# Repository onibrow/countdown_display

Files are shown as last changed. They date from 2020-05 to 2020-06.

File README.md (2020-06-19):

# Countdown Display

A low power countdown display

## Manual

### On / Off

The slide switch in the right position (closer to the edge of the device) is the "Discharge" or ON mode. The slide switch in the left position (closer to the middle of the device) is the "Charge / OFF" mode.

### Charging

To charge the battery, put the slide switch into the "Charge / OFF" mode - this will disconnect the battery from the rest of the device and enable it to be charged. At this state, the display will no longer turn on. Plug in a microUSB cable to the port and watch the indicator LED turn on. If RED, the battery is charging - if GREEN, the charge is complete. From fully discharged to fully charged, it will take about 2.5 hours.

### Safety

As this device has all of its electrical components exposed, do not touch this with wet hands or poke it with metal / conductive objects. There are safety electronics in play to prevent the battery from over-currenting and frying itself, it is generally not a great idea to mess around with LiPo batteries. 

## Features

### 128x32 OLED Display

[SSD1306](https://smile.amazon.com/gp/product/B07X35H728/ref=ppx_yo_dt_b_asin_title_o06_s00?ie=UTF8&psc=1) 128x32 OLED display compatible with Adafruit's [OLED library](https://github.com/adafruit/Adafruit_SSD1306), featuring a shut down mode for low power consumption, capable of running off 3.6V to 5V.

### Low Power

ATMega328P was chosen for the microcontroller of choice, for its low power sleep feature and small footprint. Running off of a LiPo battery, it can enter a deep sleep that consumes less that 10uA of current utilizing the external interrupt (generated using a push button) based indefinite sleep, from the [Arduino LowPower library](https://www.arduino.cc/en/Reference/ArduinoLowPower). The fuses are burned to use an 8MHz external clock and to brown out at 3V.

### RTC

A real time clock was used to keep track of the current date and time, running off of an ultra low power DS3231 and a back up coin cell. With the coin cell, the time keeping feature can run for 5 years, while the ultra low power could be directly sourced from one of the digital output pins on the ATMega to make power on and off of the RTC much easier. The Adafrtui [RTClib](https://github.com/adafruit/RTClib) was used for this chip.

### LiPo

A 40mAh LiPo battery was chosen as the main power supply for this device. Considering an ON current of about 12mA and a deep sleep current of 10uA, a quick calculation assuming that the device will be powered on for 2 minutes in any given day leaves the device an astounding 2 month life on a single charge. It is also equiped with an [MCP73831](https://www.microchip.com/wwwproducts/en/en024903) single cell, LiPo charge management controller to recharge the battery safely over a microUSB connection.

## Gallery



gif

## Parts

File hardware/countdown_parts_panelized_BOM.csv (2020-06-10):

Comment | Designator | Footprint | LCSC Part
20pF | C100 | 402 | C1554
20pF | C200 | 402 | C1554
4.7uF | C300 | 402 | C23733
4.7uF | C400 | 402 | C23733
0.1uF | C500 | 402 | C1525
0.1uF | C600 | 402 | C1525
1uF | C700 | 402 | C52923
0.1uF | C800 | 402 | C1525
Red | D100 | LED_0603 | C2286
Green | D200 | LED_0603 | C72043
330R | R100 | 402 | C25104
51k | R200 | 402 | C25794
1k | R300 | 402 | C11702
10k | R400 | 402 | C25744
10k | R500 | 402 | C25744
10k | R600 | 402 | C25744
330R | R700 | 402 | C25104
DS3231 | U100 | SOIC-8_3.9x4.9x1.27P | C107410
ATMEGA328P | U200 | TQFP-32_7.0x7.0x0.8P | C14877
MCP73831 | U300 | SOT-23-5 | C424093
BL1551 | U400 | SOT-363 | C82528
8Mhz | Y100 | SMD-5032_2P | C115962
20pF | C110 | 402 | C1554
20pF | C210 | 402 | C1554
4.7uF | C310 | 402 | C23733
4.7uF | C410 | 402 | C23733
0.1uF | C510 | 402 | C1525
0.1uF | C610 | 402 | C1525
1uF | C710 | 402 | C52923
0.1uF | C810 | 402 | C1525
Red | D110 | LED_0603 | C2286
Green | D210 | LED_0603 | C72043
330R | R110 | 402 | C25104
51k | R210 | 402 | C25794
1k | R310 | 402 | C11702
10k | R410 | 402 | C25744
10k | R510 | 402 | C25744
10k | R610 | 402 | C25744
330R | R710 | 402 | C25104
DS3231 | U110 | SOIC-8_3.9x4.9x1.27P | C107410
ATMEGA328P | U210 | TQFP-32_7.0x7.0x0.8P | C14877
MCP73831 | U310 | SOT-23-5 | C424093
BL1551 | U410 | SOT-363 | C82528
8Mhz | Y110 | SMD-5032_2P | C115962

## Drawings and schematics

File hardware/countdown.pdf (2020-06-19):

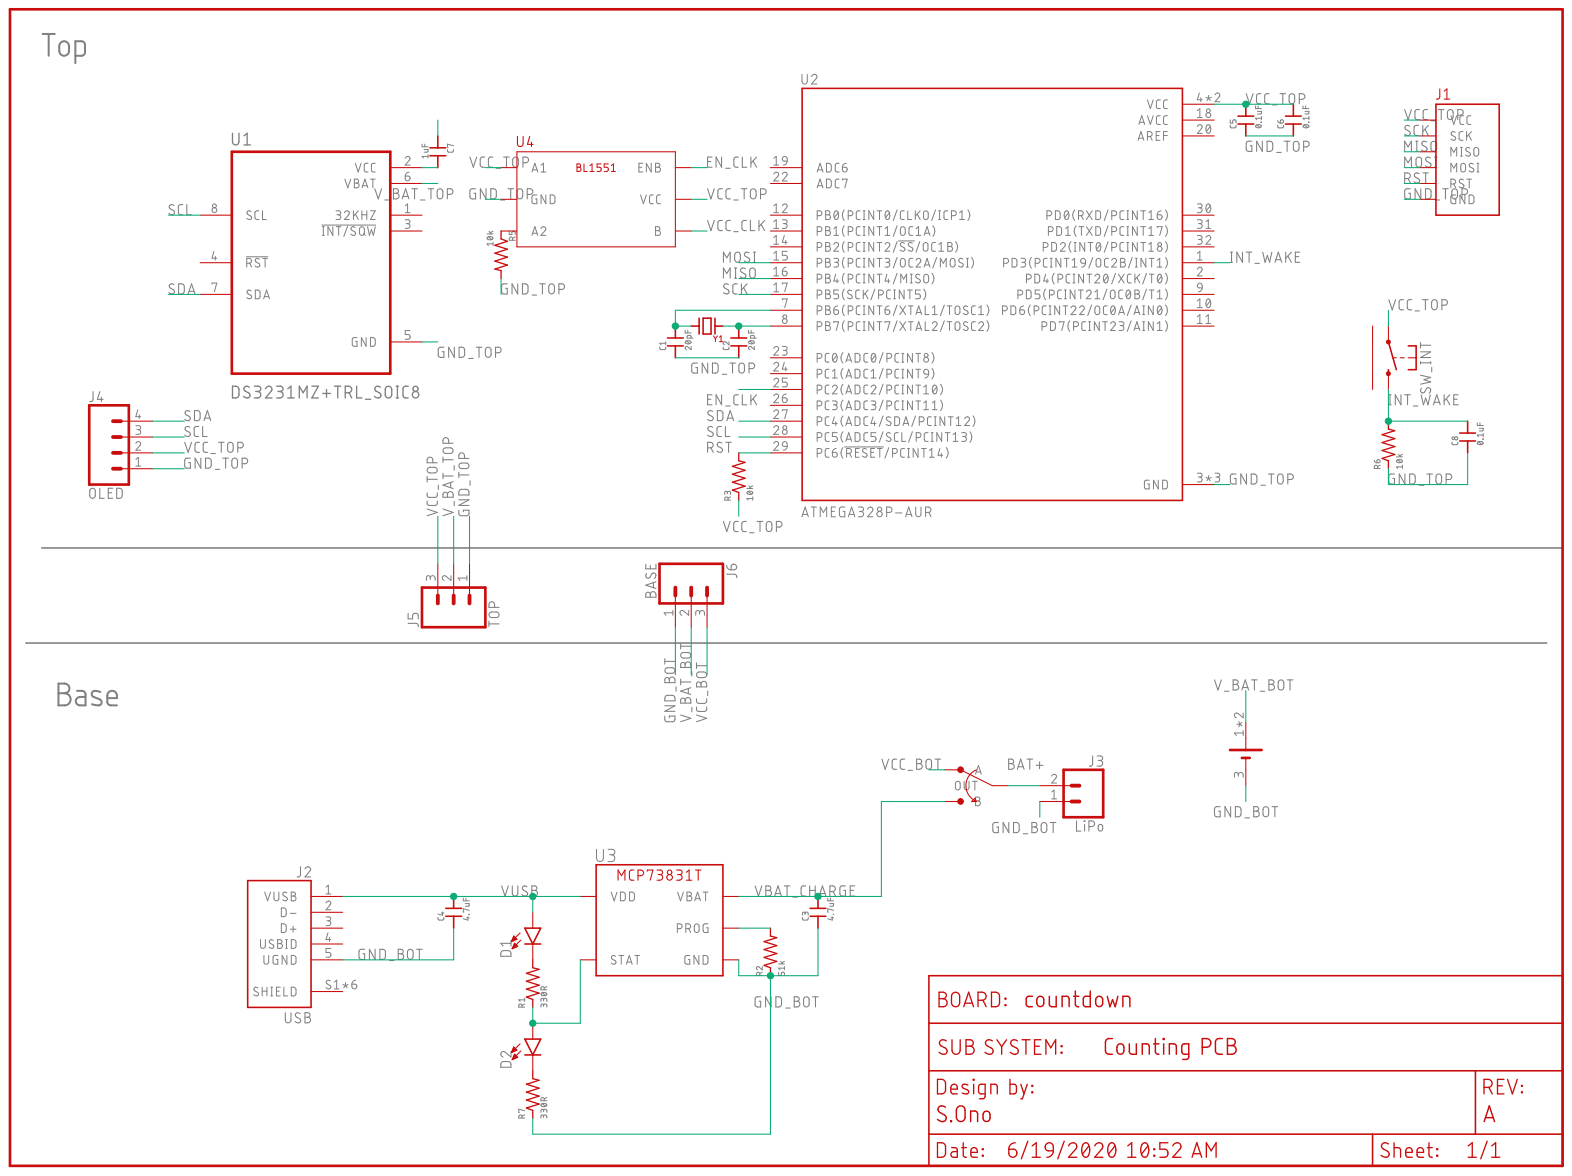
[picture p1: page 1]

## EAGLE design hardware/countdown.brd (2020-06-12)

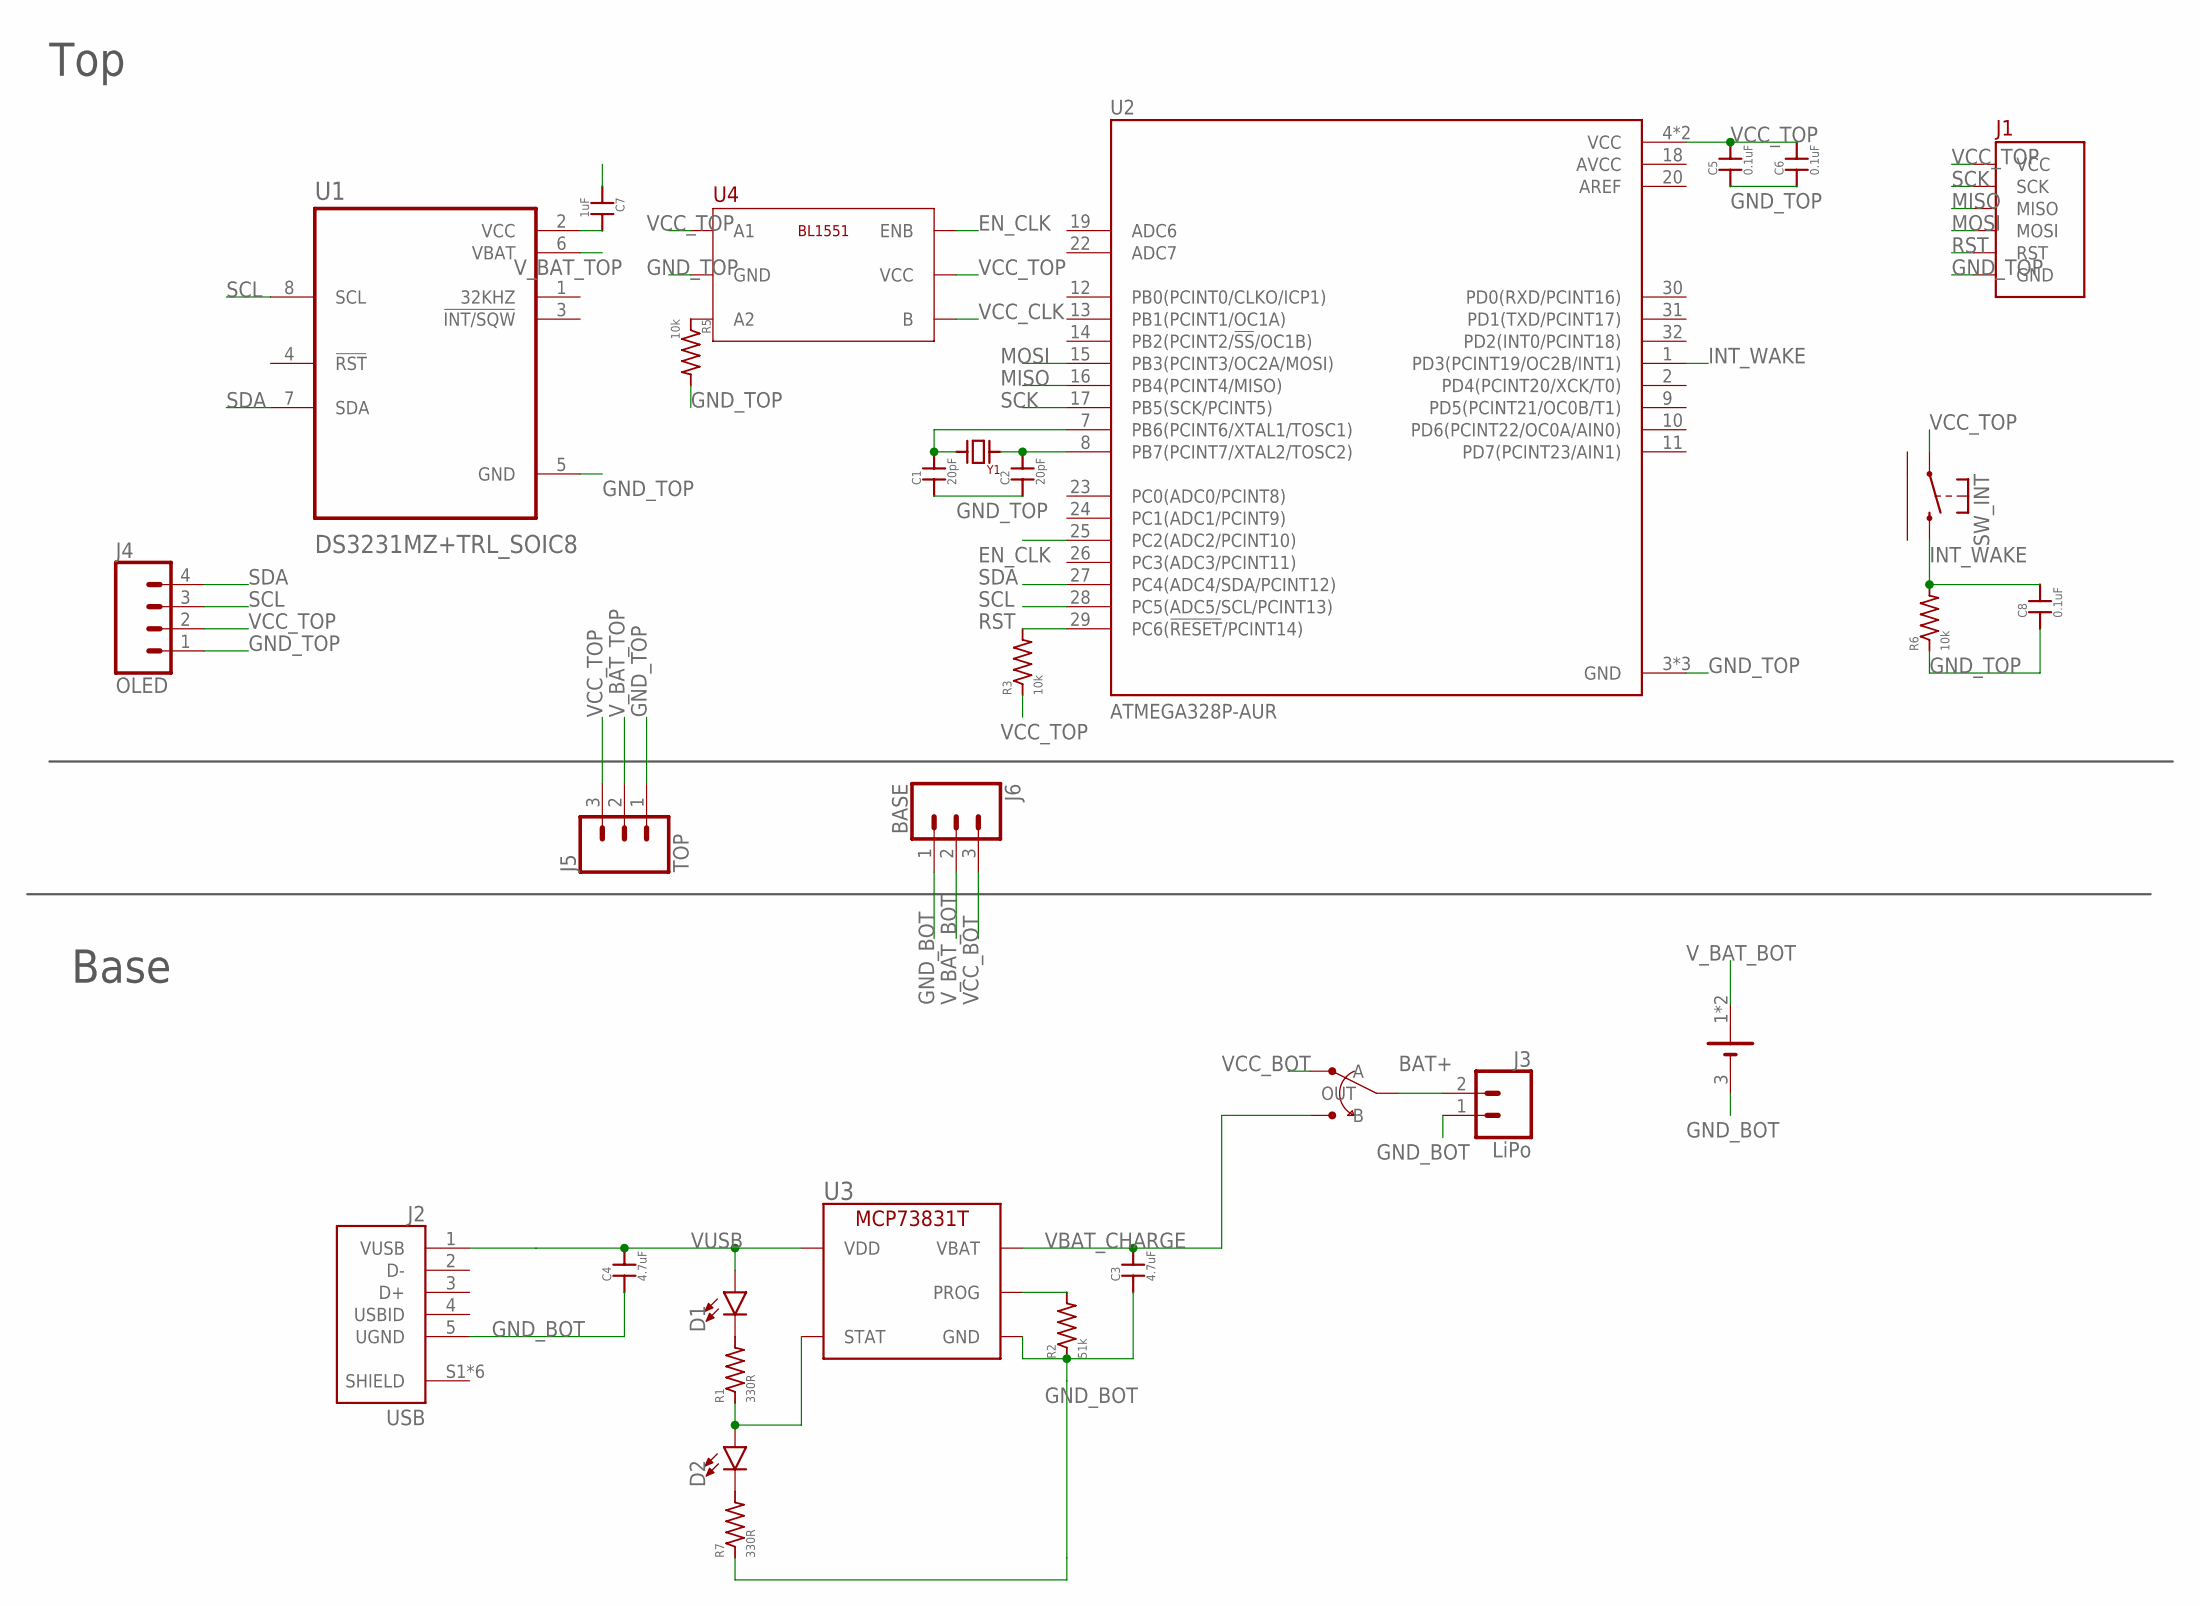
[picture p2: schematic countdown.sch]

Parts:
BT1: BK-916-TR; BAT_BK-916-TR
C1, C2: 20pF; 0402-CAP
C3, C4: 4.7uF; 0402-CAP
C5, C6, C8: 0.1uF; 0402-CAP
C7: 1uF; 0402-CAP
D1, D2: LED0603; LED-0603
J1: BURNIN
J2: USB; FCI_10103594-0001LF
J3: LiPo; 1X02
J4: OLED; 1X04_NO_SILK
J5: TOP; 1X03_NO_SILK
J6: BASE; 1X03_NO_SILK
R1, R7: 330R; R0402
R2: 51k; R0402
R3, R5, R6: 10k; R0402
SW_INT: FSMRACD
U1: DS3231MZ+TRL_SOIC8; SOIC-8
U2: ATMEGA328P-AUR; QFP80P900X900X120-32N
U3: MCP73831T; SOT-23-5
U4: BL1551; SOT-363
U$1: CL-SB-12C-12; 12C-12
Y1: CRYSTAL_5032; XTAL500X320X130N

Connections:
AREF: U2.20 (AREF)
AVCC: U2.18 (AVCC)
BAT+: J3.2, U$1.2 (OUT)
EN_CLK: U2.25 (PC2(ADC2/PCINT10)), U4.6 (ENB)
GND_BOT: BT1.3 (-), C3.1, C4.1, J2.5 (UGND), J3.1, J6.1, R2.1, R7.1, U3.2 (GND)
GND_TOP: C1.1, C2.1, C5.1, C6.1, C7.1, C8.1, J1.GND, J4.1, J5.1, R5.2, R6.1, U1.5 (GND), U2.3 (GND), U2.5 (GND), U2.21 (GND), U4.2 (GND)
INT_WAKE: C8.2, R6.2, SW_INT.P$2 (S), U2.1 (PD3(PCINT19/OC2B/INT1))
MISO: J1.MISO, U2.16 (PB4(PCINT4/MISO))
MOSI: J1.MOSI, U2.15 (PB3(PCINT3/OC2A/MOSI))
unnamed: R5.1, U4.3 (A2)
unnamed: D2.C, R7.2
unnamed: D1.C, R1.2
PROG: R2.2, U3.5 (PROG)
RST: J1.RST, R3.2, U2.29 (PC6(!RESET!/PCINT14))
SCK: J1.SCK, U2.17 (PB5(SCK/PCINT5))
SCL: J4.3, U1.8 (SCL), U2.28 (PC5(ADC5/SCL/PCINT13))
SDA: J4.4, U1.7 (SDA), U2.27 (PC4(ADC4/SDA/PCINT12))
STAT: D2.A, R1.1, U3.1 (STAT)
VBAT_CHARGE: C3.2, U3.3 (VBAT), U$1.3 (B)
VCC_BOT: J6.3, U$1.1 (A)
VCC_CLK: C7.2, U1.2 (VCC), U4.4 (B)
VCC_TOP: C5.2, C6.2, J1.3.3V (VCC), J4.2, J5.3, R3.1, SW_INT.P$1, U2.4 (VCC), U2.6 (VCC), U4.1 (A1), U4.5 (VCC)
VUSB: C4.2, D1.A, J2.1 (VUSB), U3.4 (VDD)
V_BAT_BOT: BT1.1 (+), BT1.2 (+), J6.2
V_BAT_TOP: J5.2, U1.6 (VBAT)
XTAL1: C1.2, U2.7 (PB6(PCINT6/XTAL1/TOSC1)), Y1.2 (B)
XTAL2: C2.2, U2.8 (PB7(PCINT7/XTAL2/TOSC2)), Y1.1 (A)

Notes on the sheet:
Top
Base

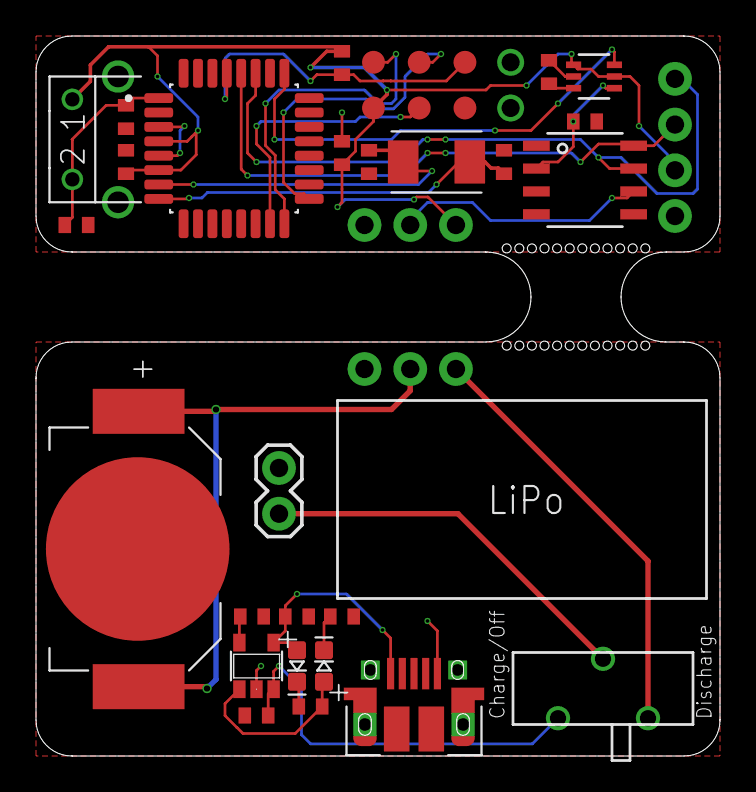
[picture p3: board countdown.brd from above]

Board: 2 copper layers, 38.0 x 40.0 mm, 30 parts (1 on the bottom side), 25 nets.

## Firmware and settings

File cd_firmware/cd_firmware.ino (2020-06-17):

#include <SPI.h>
#include <Wire.h>
#include "mac_time.h"
#include <Adafruit_GFX.h>
#include <Adafruit_SSD1306.h>
#include "RTClib.h"
#include <LowPower.h>

#define SCREEN_WIDTH 128
#define SCREEN_HEIGHT 32
#define OLED_RESET     4

#define SCREEN_TIME  5000
#define DELAY_BOUNCE  250
#define DELAY_SLEEP  1000

Adafruit_SSD1306 display(SCREEN_WIDTH, SCREEN_HEIGHT, &Wire, OLED_RESET);
RTC_DS3231 rtc;
DateTime now;
TimeSpan diff;
DateTime end_date = DateTime(2020, 9, 1, 20, 0, 0);
DateTime compile_time = DateTime(2020, 6, 17, 11, 45, 3);

const uint8_t wake_pin = 3;
const uint8_t ds_pin = 16;

void wakeUp() {
  return;
}

void setup() {
  pinMode(wake_pin, INPUT);
  pinMode(ds_pin, OUTPUT);
  digitalWrite(ds_pin, LOW);

  // OLED Display Setup {{
  if (!display.begin(SSD1306_SWITCHCAPVCC, 0x3C)) {
    for (;;);
  }
  display.dim(true);
  display.clearDisplay();
  display.display();
  display.ssd1306_command(SSD1306_DISPLAYOFF);
  // }}

  // DS3231 Setup {{
  if (! rtc.begin()) {
    for (;;);
  }
  if (rtc.lostPower()) {
    rtc.adjust(compile_time);
  // }}

    delay(5);
  }
}

void loop() {
  attachInterrupt(digitalPinToInterrupt(wake_pin), wakeUp, RISING);

  LowPower.powerDown(SLEEP_FOREVER, ADC_OFF, BOD_OFF);

  detachInterrupt(digitalPinToInterrupt(wake_pin));
  get_datetime();
}

void get_datetime() {
  display.ssd1306_command(SSD1306_DISPLAYON);

  // Load in current time
  digitalWrite(ds_pin, HIGH);
  delay(5);
  now = rtc.now();
  digitalWrite(ds_pin, LOW);
  if (now < end_date) {
    diff = end_date - now;
  }
  else {
    diff = TimeSpan(0);
  }

  if (now.hour() < 8) {
    pusheen_sleep();
  }
  else {
    pusheen_bounce();
  }
  display.ssd1306_command(SSD1306_DISPLAYOFF);
}

void draw_datetime() {
  display.clearDisplay();
  display.setTextSize(1);
  display.setTextColor(SSD1306_WHITE);
  display.setCursor(0, 4);

  // Month
  /*
    if (now.month() < 10) {
      display.print("0");
    }
    display.print(now.month());
    display.print(" Month");
    if (now.month() != 1) {
      display.print("s");
    }
    display.print("\n");
  */

  if (diff.days() < 10) {
    display.print("0");
  }
  display.print(diff.days());
  display.print(" Day");
  if (diff.days() != 1) {
    display.print("s");
  }
  display.print("\n");

  if (diff.hours() < 10) {
    display.print("0");
  }
  display.print(diff.hours());
  display.print(" Hour");
  if (diff.hours() != 1) {
    display.print("s");
  }
  display.print("\n");

  if (diff.minutes() < 10) {
    display.print("0");
  }
  display.print(diff.minutes());
  display.print(" Minute");
  if (diff.minutes() != 1) {
    display.print("s");
  }
  display.print("\n");
}

void pusheen_bounce() {
  for (uint8_t i = 0; i < round(SCREEN_TIME / DELAY_BOUNCE / 2 + 0.5); i++) {
    draw_datetime();
    display.drawBitmap(
      (display.width()  - PUSHEEN_WIDTH_BIG),
      (display.height() - PUSHEEN_HEIGHT_BIG),
      pusheen_1, PUSHEEN_WIDTH_BIG, PUSHEEN_HEIGHT_BIG, 1);
    display.display();
    delay(DELAY_BOUNCE);

    draw_datetime();
    display.drawBitmap(
      (display.width()  - PUSHEEN_WIDTH_BIG),
      (display.height() - PUSHEEN_HEIGHT_BIG),
      pusheen_2, PUSHEEN_WIDTH_BIG, PUSHEEN_HEIGHT_BIG, 1);
    display.display();
    delay(DELAY_BOUNCE);
  }
  display.clearDisplay();
  display.display();
}

void pusheen_sleep() {
  for (uint8_t i = 0; i < round(SCREEN_TIME / DELAY_SLEEP / 2 + 0.5); i++) {
    draw_datetime();
    display.drawBitmap(
      (display.width()  - PUSHEEN_WIDTH_BIG),
      (display.height() - PUSHEEN_HEIGHT_BIG),
      pusheen_1_sleep, PUSHEEN_WIDTH_BIG, PUSHEEN_HEIGHT_BIG, 1);
    display.display();
    delay(DELAY_SLEEP);

    draw_datetime();
    display.drawBitmap(
      (display.width()  - PUSHEEN_WIDTH_BIG),
      (display.height() - PUSHEEN_HEIGHT_BIG),
      pusheen_2_sleep, PUSHEEN_WIDTH_BIG, PUSHEEN_HEIGHT_BIG, 1);
    display.display();
    delay(DELAY_SLEEP);
  }
  display.clearDisplay();
  display.display();
}

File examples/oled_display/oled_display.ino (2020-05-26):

#include <SPI.h>
#include <Wire.h>
#include <Adafruit_GFX.h>
#include <Adafruit_SSD1306.h>

#define SCREEN_WIDTH 128 // OLED display width, in pixels
#define SCREEN_HEIGHT 32 // OLED display height, in pixels

#define OLED_RESET     4 // Reset pin # (or -1 if sharing Arduino reset pin)
Adafruit_SSD1306 display(SCREEN_WIDTH, SCREEN_HEIGHT, &Wire, OLED_RESET);

#define NUMFLAKES     10 // Number of snowflakes in the animation example

#define LOGO_HEIGHT   16
#define LOGO_WIDTH    16
static const unsigned char PROGMEM logo_bmp[] =
{ B00000000, B11000000,
  B00000001, B11000000,
  B00000001, B11000000,
  B00000011, B11100000,
  B11110011, B11100000,
  B11111110, B11111000,
  B01111110, B11111111,
  B00110011, B10011111,
  B00011111, B11111100,
  B00001101, B01110000,
  B00011011, B10100000,
  B00111111, B11100000,
  B00111111, B11110000,
  B01111100, B11110000,
  B01110000, B01110000,
  B00000000, B00110000
};

void setup() {
  Serial.begin(9600);

  if (!display.begin(SSD1306_SWITCHCAPVCC, 0x3C)) { // Address 0x3C for 128x32
    Serial.println(F("SSD1306 allocation failed"));
    for (;;); // Don't proceed, loop forever
  }

  display.clearDisplay();
  //
  //  display.drawPixel(10, 10, SSD1306_WHITE);
  //  display.display();
  //  delay(2000);
  //
  //  testdrawchar();      // Draw characters of the default font
  //
  //  testdrawstyles();    // Draw 'stylized' characters
  //
  //  testscrolltext();    // Draw scrolling text
  //
  //  testdrawbitmap();    // Draw a small bitmap image
  test_text();
  print_time();

  //  testanimate(logo_bmp, LOGO_WIDTH, LOGO_HEIGHT); // Animate bitmaps
}

void loop() {
}

void testdrawchar(void) {
  display.clearDisplay();

  display.setTextSize(1);      // Normal 1:1 pixel scale
  display.setTextColor(SSD1306_WHITE); // Draw white text
  display.setCursor(0, 0);     // Start at top-left corner
  display.cp437(true);         // Use full 256 char 'Code Page 437' font

  // Not all the characters will fit on the display. This is normal.
  // Library will draw what it can and the rest will be clipped.
  for (int16_t i = 0; i < 256; i++) {
    if (i == '\n') display.write(' ');
    else          display.write(i);
  }

  display.display();
  delay(5000);
}

void testdrawstyles(void) {
  display.clearDisplay();

  display.setTextSize(1);             // Normal 1:1 pixel scale
  display.setTextColor(SSD1306_WHITE);        // Draw white text
  display.setCursor(0, 0);            // Start at top-left corner
  display.println(F("Hello, world!"));

  display.setTextColor(SSD1306_BLACK, SSD1306_WHITE); // Draw 'inverse' text
  display.println(3.141592);

  display.setTextSize(2);             // Draw 2X-scale text
  display.setTextColor(SSD1306_WHITE);
  display.print(F("0x")); display.println(0xDEADBEEF, HEX);

  display.display();
  delay(2000);
}

void print_time(void) {
  display.clearDisplay();

  display.setTextSize(2);
  display.setTextColor(SSD1306_WHITE);
  display.setCursor(16, 0);

  // Get Date
  display.println(F("2M 31D 03H"));
  // End Get Date

  display.display();
  delay(5000);
}

void test_text(void) {
  display.clearDisplay();

  display.setTextSize(2);
  display.setTextColor(SSD1306_WHITE);
  display.setCursor(0, 0);

  // Get Date
  display.println(F("0123456789ABCDEFGHIJKLMNOPQRSTUV"));
  // End Get Date

  display.display();
  delay(5000);
}

void testscrolltext(void) {
  display.clearDisplay();

  display.setTextSize(2); // Draw 2X-scale text
  display.setTextColor(SSD1306_WHITE);
  display.setCursor(10, 0);
  display.println(F("scroll"));
  display.display();      // Show initial text
  delay(100);

  // Scroll in various directions, pausing in-between:
  display.startscrollright(0x00, 0x0F);
  delay(2000);
  display.stopscroll();
  delay(1000);
  display.startscrollleft(0x00, 0x0F);
  delay(2000);
  display.stopscroll();
  delay(1000);
  display.startscrolldiagright(0x00, 0x07);
  delay(2000);
  display.startscrolldiagleft(0x00, 0x07);
  delay(2000);
  display.stopscroll();
  delay(1000);
}

void testdrawbitmap(void) {
  display.clearDisplay();

  display.drawBitmap(
    (display.width()  - LOGO_WIDTH ) / 2,
    (display.height() - LOGO_HEIGHT) / 2,
    logo_bmp, LOGO_WIDTH, LOGO_HEIGHT, 1);
  display.display();
  delay(1000);
}

#define XPOS   0 // Indexes into the 'icons' array in function below
#define YPOS   1
#define DELTAY 2

void testanimate(const uint8_t *bitmap, uint8_t w, uint8_t h) {
  int8_t f, icons[NUMFLAKES][3];

  // Initialize 'snowflake' positions
  for (f = 0; f < NUMFLAKES; f++) {
    icons[f][XPOS]   = random(1 - LOGO_WIDTH, display.width());
    icons[f][YPOS]   = -LOGO_HEIGHT;
    icons[f][DELTAY] = random(1, 6);
    Serial.print(F("x: "));
    Serial.print(icons[f][XPOS], DEC);
    Serial.print(F(" y: "));
    Serial.print(icons[f][YPOS], DEC);
    Serial.print(F(" dy: "));
    Serial.println(icons[f][DELTAY], DEC);
  }

  for (;;) { // Loop forever...
    display.clearDisplay(); // Clear the display buffer

    // Draw each snowflake:
    for (f = 0; f < NUMFLAKES; f++) {
      display.drawBitmap(icons[f][XPOS], icons[f][YPOS], bitmap, w, h, SSD1306_WHITE);
    }

    display.display(); // Show the display buffer on the screen
    delay(200);        // Pause for 1/10 second

    // Then update coordinates of each flake...
    for (f = 0; f < NUMFLAKES; f++) {
      icons[f][YPOS] += icons[f][DELTAY];
      // If snowflake is off the bottom of the screen...
      if (icons[f][YPOS] >= display.height()) {
        // Reinitialize to a random position, just off the top
        icons[f][XPOS]   = random(1 - LOGO_WIDTH, display.width());
        icons[f][YPOS]   = -LOGO_HEIGHT;
        icons[f][DELTAY] = random(1, 6);
      }
    }
  }
}

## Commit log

2020-05-29 Fix compilations and add more squish to pusheen
    [pusheen.ino]
2020-05-31 start hardware
    [countdown.brd, countdown.sch]
2020-06-01 make debug version
    [countdown_debug.brd, countdown_debug.sch]
2020-06-02 prepare for order
    [countdown.sch, countdown_debug.brd, countdown_debug.sch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]
2020-06-10 jlc order done
    [countdown.brd, countdown.sch, countdown_debug.brd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]
2020-06-12 small fixes to board from debugging
    [countdown.brd, countdown.sch, countdown_parts.csv]
2020-06-19 reorganize test sketches, add schematic pdf
